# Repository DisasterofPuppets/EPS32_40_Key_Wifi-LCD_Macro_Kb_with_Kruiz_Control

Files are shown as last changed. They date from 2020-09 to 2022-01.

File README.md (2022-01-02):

# Twitch 40 Key Macro Keyboard using Kruiz Control
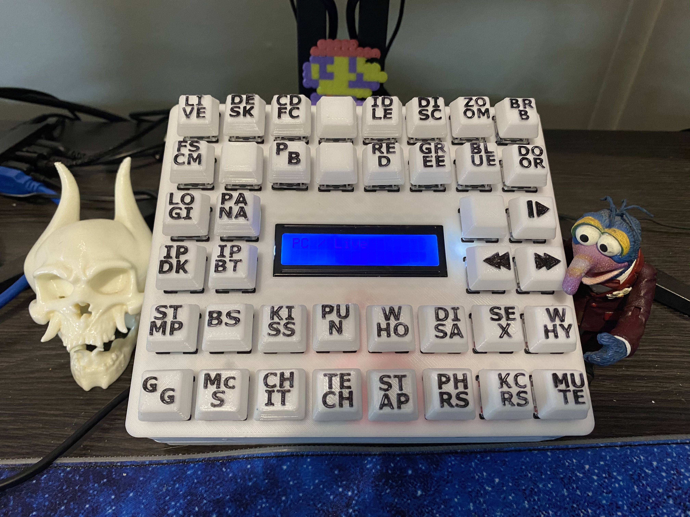
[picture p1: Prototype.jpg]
GitHub Logo


Disaster of Puppets
YouTube: Http://disasterofpuppets.com
Twitch: Https://twitch.tv/disasterofpuppets

A 40 Key macro keyboard running off an ESP32, using IRC messages to 
trigger commands in Kruiz Control and automate OBS Studio scenes etc.
LCD Screen shows the current Scene / mute status. 
Oh, and it's wireless.

Using https://github.com/fredimachado/ArduinoIRC
Kruiz Control https://github.com/Kruiser8/Kruiz-Control

*It is assumed you have already installed Kruiz-Control. If not refer to documentation from the link above.*
*It is also assumed you know how to install any required Arduino Libraries. See the below as a starting point.*

For the ESP32 Board: https://randomnerdtutorials.com/installing-the-esp32-board-in-arduino-ide-windows-instructions/
Generic Library addition: https://www.youtube.com/watch?v=M6PZOqNHKxM

**************************************************************************************

## Required Materials:

* 40 x Cherry MX switches / your choice of Key switches.
Example: https://www.ebay.com.au/itm/70Pcs-3-Pin-Mechanical-Keyboard-Switch-Blue-Plate-Gateron-Keyboard-RGB-Series/233659187775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

* Button Caps - I printed my own and they are included as blanks or custom buttons below.

* ESP-32 ESP32S
Example: https://www.ebay.com.au/itm/ESP-32-ESP32S-Development-Board-2-4GHz-WiFi-Bluetooth-Antenna-CP2102-Module-AU/114199620604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

* 1602 16X2 LCD Display IIC/I2C/TWI/SPI Serial Interface Module
Example: https://www.ebay.com.au/itm/1602-16X2-LCD-Display-IIC-I2C-TWI-SPI-Serial-Interface-Module-For-Arduino/324135354058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

* 3D printer or access to someone who can print the files for you

**************************************************************************************
## Instructions

**Step # 1**

Complete the fields in Creds.h and save

**Step # 2**

Print the base.stl and lid.stl files
I have also included BlankButtonMaster.3mf which should allow you to make most letter combinations for custom blank keys. 
If there is button label you are unable to make with this let me know and I should be able to update the file for future users.

**Step # 3**

Wire as per 40KeyWifiSDKCWiring.png

**Step # 4**

Change the button coding to your specific needs in ESP32TwitchMACROKB.ino
Also make sure to replace 'Changemetoyourbotname' to your botname
I uploaded the sketch to the board by choosing 'DOIT ESP32 DEVKIT V1' 

**Step # 5**

Using ExampleTriggers Code for Kruiz Control.txt insert the specific commands into Triggers.txt

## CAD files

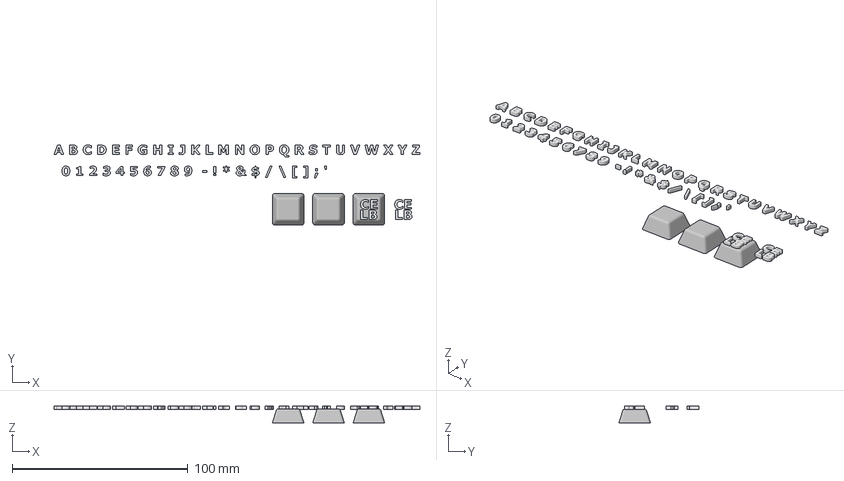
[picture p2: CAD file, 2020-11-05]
BlankButtonTemplate.3mf
208.4 x 45.7 x 9.50 mm

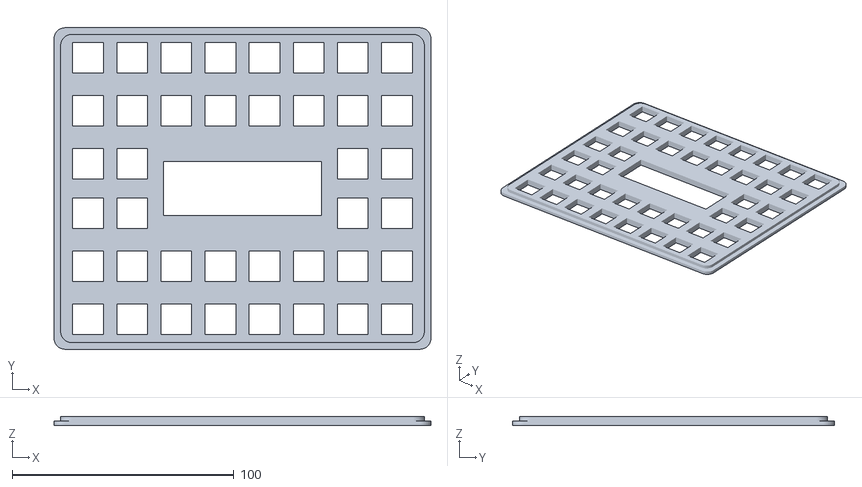
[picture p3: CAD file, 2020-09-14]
lid.stl
170.0 x 145.0 x 4.00

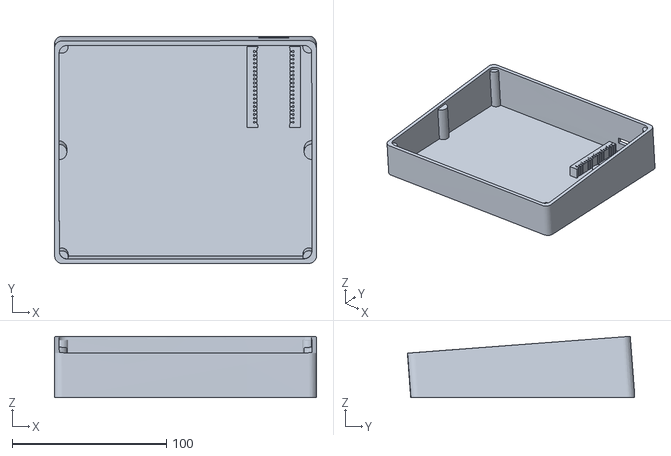
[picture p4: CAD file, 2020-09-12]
base.stl
170.1 x 147.5 x 39.8

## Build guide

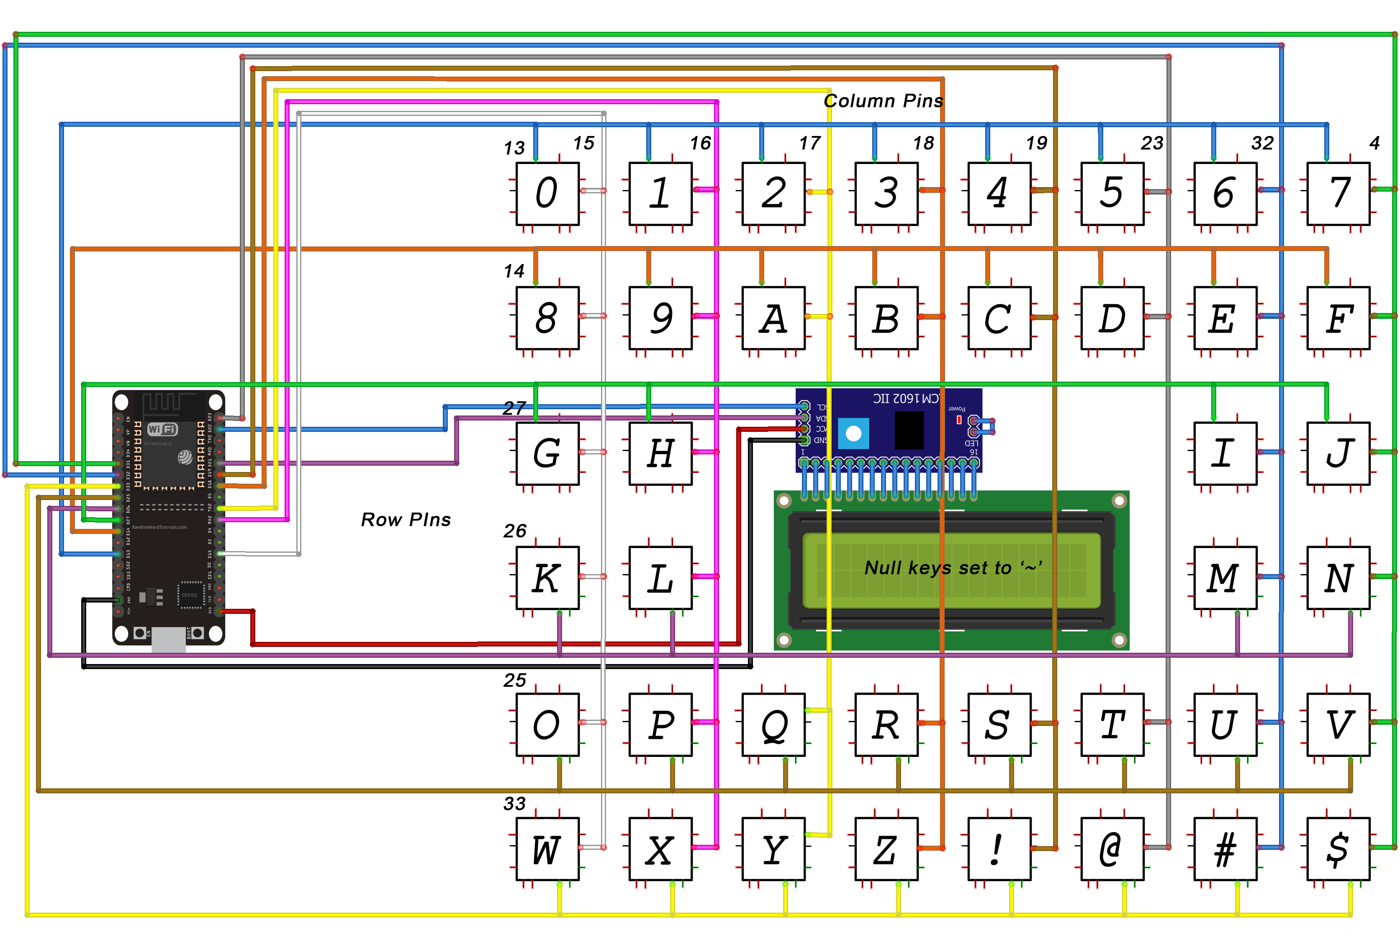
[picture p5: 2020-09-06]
40KeyWifiSDKCWiring.png

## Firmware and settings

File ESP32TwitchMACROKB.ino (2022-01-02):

/*******************************************************************
Disaster of Puppets
YouTube: Http://disasterofpuppets.com
Twitch: Https://twitch.tv/disasterofpuppets

A 40 Key macro keyboard running off an ESP32, using IRC messages to 
trigger commands in Kruiz Control and automate OBS Studio scenes etc.
LCD Screen shows the current button / Scene in play
Oh, and it's wireless

I used DOIT ESP32 DEVKIT V1 as the board to upload this code
Don't forget to push the flash button on the ESP32 when uploading

Using https://github.com/fredimachado/ArduinoIRC
Kruiz Control https://github.com/Kruiser8/Kruiz-Control


// Don't forget to edit Creds.h
 *******************************************************************/
#include <WiFi.h> 
#include <IRCClient.h>
#include "Creds.h"
#include <Keypad.h>
#include <Wire.h>
#include <LiquidCrystal_I2C.h>

//-------------EDIT in Creds.h----------
char ssid[] = WIFI_SSID;       // your network SSID (name)
char password[] = WIFI_PASS;  // your network key

//------------------------------

bool muted = 1;
bool logi = 1;
bool SJ = 1;
bool AS = 1;
bool GTG = 1;
bool cdcam = 1;
bool panacam = 1;
bool botscam = 1;
int led = LED_BUILTIN;
String ircChannel = "";
int runonce = 0;
WiFiClient wiFiClient;
IRCClient client(IRC_SERVER, IRC_PORT, wiFiClient);

int keypress = 100; // delay between keypad press and release
const byte ROWS = 6;
const byte COLS = 8;

char hexaKeys[ROWS][COLS] = 
{

    {'0', '1', '2', '3', '4', '5', '6', '7'}, 
    {'8', '9', 'A', 'B', 'C', 'D', 'E', 'F'},
    {'G', 'H', '~', '~', '~', '~', 'I', 'J'},
    {'K', 'L', '~', '~', '~', '~', 'M', 'N'},
    {'O', 'P', 'Q', 'R', 'S', 'T', 'U', 'V'},
    {'W', 'X', 'Y', 'Z', '!', '@', '#', '$'},
};

byte rowPins[ROWS] = {13, 14, 27, 26, 25, 33}; //13,14,27,26,25,33 
byte colPins[COLS] = {15,16,17,18,19,23,32,4}; // PINS 15,RX2,TX2,18,19,23,32,4

Keypad customKeypad = Keypad( makeKeymap(hexaKeys), rowPins, colPins, ROWS, COLS); 

LiquidCrystal_I2C lcd(0x27,16,2); 


// put your setup code here, to run once:
void setup() {

  pinMode(led, OUTPUT);
  Serial.begin(115200);
  
  // Set WiFi to station mode and disconnect from an AP if it was Previously
  // connected
  WiFi.mode(WIFI_STA);
  WiFi.disconnect();
  delay(100);

  // Attempt to connect to Wifi network:
  Serial.print("Connecting Wifi: ");
  Serial.println(ssid);
  WiFi.begin(ssid, password);
  while (WiFi.status() != WL_CONNECTED) {
    Serial.print(".");
    delay(500);
  }
  Serial.println("");
  Serial.println("WiFi connected");
  Serial.println("IP address: ");
  IPAddress ip = WiFi.localIP();
  Serial.println(ip);

  ircChannel = "#" + twitchChannelName;

  client.setCallback(callback);

lcd.init(); // initialize the lcd
lcd.init();
lcd.backlight();

}

void loop() {

  // Try to connect to chat. If it loses connection try again
  if (!client.connected()) {
    Serial.println("Attempting to connect to " + ircChannel );
    // Attempt to connect
    // Second param is not needed by Twitch
    if (client.connect(TWITCH_BOT_NAME, "", TWITCH_OAUTH_TOKEN)) {
      client.sendRaw("JOIN " + ircChannel);
      Serial.println("connected and ready to rock");


if (runonce == 0){
//run your default state here, eg I duplicated button 1's functionality

  //  sendTwitchMessage("/w drpuppetmaster !Live"); I would't rcommend. If you move around or disconnect it will switch to this on start up;
    delay(keypress);
    lcd.setCursor(0,0);
    lcd.print("D.I.Y. Stream Deck");
    lcd.setCursor(0,1);
    lcd.print("                ");
    runonce = 1;
}

      //Uncomment below if you want a twitch chat message on connect
      //sendTwitchMessage("Ready to go Boss!");
    } else {
      Serial.println("failed... try again in 5 seconds");
      // Wait 5 seconds before retrying
      delay(5000);
    }
    return;
  }
  client.loop();

//*********** Keypad Matrix *************
char customKey = customKeypad.getKey();
 
if (customKey){
     switch (customKey){

// ROW 1-------------------------------------------        


// Live   
    
  case '0':
    // Send command to your bot to trigger the Kruiz Control command
    Serial.println("0");
    sendTwitchMessage("/w drpuppetmaster !Live");
    delay(keypress);
    lcd.setCursor(0,0);
    lcd.print("                ");
    lcd.setCursor(0,0);
    lcd.print("PC / Live");
  break;

// Craft Desk

  case '1':
    Serial.println("1");
    sendTwitchMessage("/w drpuppetmaster !Craft");
    delay(keypress);
    lcd.setCursor(0,0);
    lcd.print("                ");
    lcd.setCursor(0,0);
    lcd.print("Craft Desk");
  break;

// Craft Desk FullScreen Cam

  case '2':
    Serial.println("2");
    sendTwitchMessage("/w drpuppetmaster !Craft2");
    delay(keypress);
    lcd.setCursor(0,0);
    lcd.print("                ");
    lcd.setCursor(0,0);
    lcd.print("Craft FaceCam");
  break;

// Spare

  case '3':
    Serial.println("3");
    sendTwitchMessage("/w drpuppetmaster !Censor");
    delay(keypress);
  break;

// Idle

  case '4':
    Serial.println("4");
    sendTwitchMessage("/w drpuppetmaster !Idle");
    delay(keypress);
    lcd.setCursor(0,0);
    lcd.print("                ");
    lcd.setCursor(0,0);
    lcd.print("Idle");

  break;

//Disclaimer

  case '5':
    Serial.println("5");
    sendTwitchMessage("/w drpuppetmaster !Disclaimer");
    delay(keypress);
    lcd.setCursor(0,0);
    lcd.print("                ");
    lcd.setCursor(0,0);
    lcd.print("Disclaimer");

  break;

// Zoom

  case '6':
    Serial.println("6");
    sendTwitchMessage("/w drpuppetmaster !Zoomies");
    delay(keypress);
    lcd.setCursor(0,0);
    lcd.print("                ");
    lcd.setCursor(0,0);
    lcd.print("Zoom");


  break;

// BRB
  case '7':
    Serial.println("7");        
    sendTwitchMessage("/w drpuppetmaster !Brb");
    delay(keypress);
    lcd.setCursor(0,0);
    lcd.print("                ");
    lcd.setCursor(0,0);
    lcd.print("BRB");

  break;

// ROW 2 ---------------------------------

// Fullscreen PC Webcam

  case '8':
    Serial.println("8");
    sendTwitchMessage("/w drpuppetmaster !FSCam");
    delay(keypress);
    lcd.setCursor(0,0);
    lcd.print("                ");
    lcd.setCursor(0,0);
    lcd.print("FS Cam");

  break;

//Spare

  case '9':
    Serial.println("9");
    delay(keypress);
  break;

// Dodgy Paintbrush Time
  case 'A':
    Serial.println("A");
    sendTwitchMessage("/w drpuppetmaster !PB");
    delay(keypress);           
  break;

//Spare
  case 'B':
    Serial.println("B");
    delay(keypress);
  break;

//Red
  case 'C':
    Serial.println("C");
    sendTwitchMessage("/w drpuppetmaster !red");
    delay(keypress);
  break;

//Green
  case 'D':
    Serial.println("D");
    sendTwitchMessage("/w drpuppetmaster !green");
    delay(keypress);
  break;

//Blue
  case 'E':
    Serial.println("E");
    sendTwitchMessage("/w drpuppetmaster !blue");
    delay(keypress);
  break;

//DoorPrize
  case 'F':
    Serial.println("F");
    sendTwitchMessage("/w drpuppetmaster !Door");
    delay(keypress);
    lcd.setCursor(0,0);
    lcd.print("                ");
    lcd.setCursor(0,0);
    lcd.print("Door Prize");
  break;

// ROW 3 ---------------------------------

// Logitech Webcam Toggle

  case 'G':
    Serial.println("G");
    if (logi) {
      sendTwitchMessage("/w drpuppetmaster !Logitechhide");
      delay(keypress);
      logi = 0;
    }
    else if (!logi) {
      sendTwitchMessage("/w drpuppetmaster !Logitechshow");
      delay(keypress);
      logi = 1;     
    }
    break;

// Panasonic Cam Toggle

  case 'H':
    Serial.println("H");
    if (panacam) {
      sendTwitchMessage("/w drpuppetmaster !Panahide");
      delay(keypress);
      panacam = 0;
    }
    else if (!panacam) {
      sendTwitchMessage("/w drpuppetmaster !Panashow");
      delay(keypress);
      panacam = 1;     
    }
    break;
    
// Spare

  case 'I':
    Serial.println("I");
    sendTwitchMessage("/w drpuppetmaster !Celeb");
    delay(keypress);
  break;

// Spare

  case 'J':
    Serial.println("J");
      if (SJ) {
      sendTwitchMessage("/w drpuppetmaster !Scarlet");;
      delay(keypress);
      SJ = 0;
    }
    else if (!SJ) {
      sendTwitchMessage("/w drpuppetmaster !ScarlettOff");
      delay(keypress);
      SJ = 1;     
    }
    break;
          
    
// ROW 4 ---------------------------------


//Iphone Desk Cam Toggle

  case 'K':
    Serial.println("K");
    if (cdcam) {
      sendTwitchMessage("/w drpuppetmaster !CDhide");
      delay(keypress);
      cdcam = 0;
    }
    else if (!cdcam) {
      sendTwitchMessage("/w drpuppetmaster !CDshow");
      delay(keypress);
      cdcam = 1;     
    }
    break;

// Iphone Bot Cam Toggle
  
  case 'L':
    Serial.println("L");
    if (botscam) {
      sendTwitchMessage("/w drpuppetmaster !bothide");
      delay(keypress);
      botscam = 0;
    }
    else if (!botscam) {
      sendTwitchMessage("/w drpuppetmaster !botshow");
      delay(keypress);
      botscam = 1;     
    }
    break;

//Nulls

  case '~':
    Serial.println("~ NULL ~");
    delay(keypress);
  break;

// Spare

  case 'M':
      Serial.println("M");
      if (AS) {
      sendTwitchMessage("/w drpuppetmaster !Arnie");;
      delay(keypress);
      AS = 0;
    }
    else if (!AS) {
      sendTwitchMessage("/w drpuppetmaster !ArnieOff");
      delay(keypress);
      AS = 1;     
    }
  break;

// Spare

  case 'N':
      Serial.println("N");
      if (GTG) {
      sendTwitchMessage("/w drpuppetmaster !Gandalf");;
      delay(keypress);
      GTG = 0;
    }
    else if (!GTG) {
      sendTwitchMessage("/w drpuppetmaster !GandalfOff");
      delay(keypress);
      GTG = 1;     
    }
  break;          

// ROW 5 ---------------------------------

// Stamp

  case 'O':
    Serial.println("O");
    sendTwitchMessage("/w drpuppetmaster !Stamp");
    delay(keypress);
  break;

// BS

  case 'P':
    Serial.println("P");
    sendTwitchMessage("/w drpuppetmaster !BS");
    delay(keypress);
  break;

// KISS

  case 'Q':
    Serial.println("Q");
    sendTwitchMessage("/w drpuppetmaster !Kiss");
    delay(keypress);
  break;

//PUN

  case 'R':
    Serial.println("R");
    sendTwitchMessage("/w drpuppetmaster !Pun");
    delay(keypress);
  break;

// Who are these people?

  case 'S':
    Serial.println("S");
    sendTwitchMessage("/w drpuppetmaster !Who");
    delay(keypress);
  break;

// I disagree

  case 'T':
    Serial.println("T");
    sendTwitchMessage("/w drpuppetmaster !Disagree");
    delay(keypress);
  break;

// Sexytimes

  case 'U':
    Serial.println("U");
    sendTwitchMessage("/w drpuppetmaster !Sex");
    delay(keypress);
  break;

// Why is / isn't it working gif?

  case 'V':
    Serial.println("V");
    sendTwitchMessage("/w drpuppetmaster !Why");
    delay(keypress);
  break;       

// ROW 6 ------------------------------

// GG

  case 'W': 
    Serial.println("W");
    sendTwitchMessage("/w drpuppetmaster !Goodgame");
    delay(keypress);
  break;

// McScuse me          

  case 'X':
    Serial.println("X");
    sendTwitchMessage("/w drpuppetmaster !McScuseme");
    delay(keypress);
  break;

// Cheese it

  case 'Y':
    Serial.println("Y");
    sendTwitchMessage("/w drpuppetmaster !Cheeseit");
    delay(keypress);
  break;

// Tech support

  case 'Z':
    Serial.println("Z");
    sendTwitchMessage("/w drpuppetmaster !TechCall");
    delay(keypress);
  break;

// Sthap it

  case '!':
    Serial.println("!");
    sendTwitchMessage("/w drpuppetmaster !Sthapit");
    delay(keypress);
  break;   

// Phrasing

  case '@':
    Serial.println("@");
    sendTwitchMessage("/w drpuppetmaster !Phrasing");
    delay(keypress);
  break;   

// Kruiz Control Reset

  case '#':
    Serial.println("#");
    sendTwitchMessage("/w drpuppetmaster !Reset");
    delay(keypress);
  break;   

// Mute

  case '$':
    Serial.println("$");
    if (muted) {
      sendTwitchMessage("/w drpuppetmaster !Mute");
      delay(keypress);
      lcd.setCursor(0,1);
      lcd.print("                ");
      lcd.setCursor(0,1);
      lcd.print("***MUTED***");
      muted = 0;
    }
    else if (!muted) {
      sendTwitchMessage("/w drpuppetmaster !UnMute");
      delay(keypress);
      lcd.setCursor(0,1);
      lcd.print("                ");
      muted = 1;     
    }
    break;
            
            
     }
  }
  
}

void sendTwitchMessage(String message) {
  client.sendMessage(ircChannel, message);
}

void callback(IRCMessage ircMessage) {
  //Serial.println("In CallBack");

  if (ircMessage.command == "PRIVMSG" && ircMessage.text[0] != '\001') {
    //Serial.println("Passed private message.");
    ircMessage.nick.toUpperCase();

    String message("<" + ircMessage.nick + "> " + ircMessage.text);

    //prints chat to serial
    Serial.println(message);

    for (int i = 0; i < 6; i++) {
      digitalWrite(led, HIGH);
      delay(50);
      digitalWrite(led, LOW);
      delay(25);
    }

    return;
  }
}

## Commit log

2020-08-31 Initial outline for testing
    Currently connects and responds and displays chat in serial monitor
    Pending Matrix testing and LCD functionality
2020-09-12 updated to include esp mount
    [base.stl]
2020-09-12 Add files via upload
    fixed esp mount for more LCD clearance
    [base.stl]
2020-10-28 Blank button template
    A - Z
    0 - 9
    and some special chars.
    [BlankButtonTemplate.3mf]
2020-11-05 fixed issue with button
    [BlankButtonTemplate.3mf]
